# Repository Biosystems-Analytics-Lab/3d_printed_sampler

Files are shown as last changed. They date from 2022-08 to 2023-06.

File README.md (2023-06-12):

# 3D Printed Water Sampler

This repository includes materials for 3D printing a swinging water sample bottle holder. The sampler attachment holds a 1L sample bottle using a cable tie. The attachment screws on a standard telescoping pole (e.g., a paint roller pole). The sampler pivots such that the sample bottle can be easily filled with water. For each assembly, two washers, one bolt, and one nut with the following specs are required (all stainless steel):

- Bolts: ¼”-20 x 2-½”
- Nuts: ¼”-20
- Fender washers: ¼” x 1”

The `hardware.pdf` file includes images for the nuts, bolts, and washers we used to assemble the swing sampler.  

Be careful not to overtighten the threaded portion of the assembly onto a paint pole or other attachment. It may split the threaded body in half.

The design was created by Adam Rok and Jay Campbell in the Biological and Agricultural Engineering Department at NC State University in 2022. The designs were first published online on 26 Aug 2022.

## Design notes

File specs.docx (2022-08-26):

Bottle Holder

- Estimated printing time - Approx 12 hours
- Material:
  - Type - PLA, recommend ABS
  - Estimated amount - 127.4g, 42.71m
  - Estimated price - $3.82
- Print settings:
  - Nozzle temperature - 205 C
  - Bed temperature - 60 C
  - Layer height - 0.20mm
  - Infill density - 30
  - Infill pattern - Cubic
  - Bottom layers - 5
  - Top layers - 5
  - Shells - 2
  - Support for holes and overhangs
  - Raft - 5 layers, 3 solid

Threaded Mount

- Uses a 1/4-20 bolt as the connection / pivot point when attaching to the bottle holder
- Estimated printing time - Approx 3.5 hours
- Material:
  - Type - PLA, recommend ABS
  - Estimated amount - 39.0g, 13.08m
  - Estimated price - $1.17
- Print settings:
  - Nozzle temperature - 205 C
  - Bed temperature - 60 C
  - Layer height - 0.20mm
  - Infill density - 50
  - Infill pattern - Cubic
  - Bottom layers - 5
  - Top layers - 5
  - Shells - 2
  - Support used for hole and threads
  - Raft - 5 layers, 3 solid

Assembled Sampler

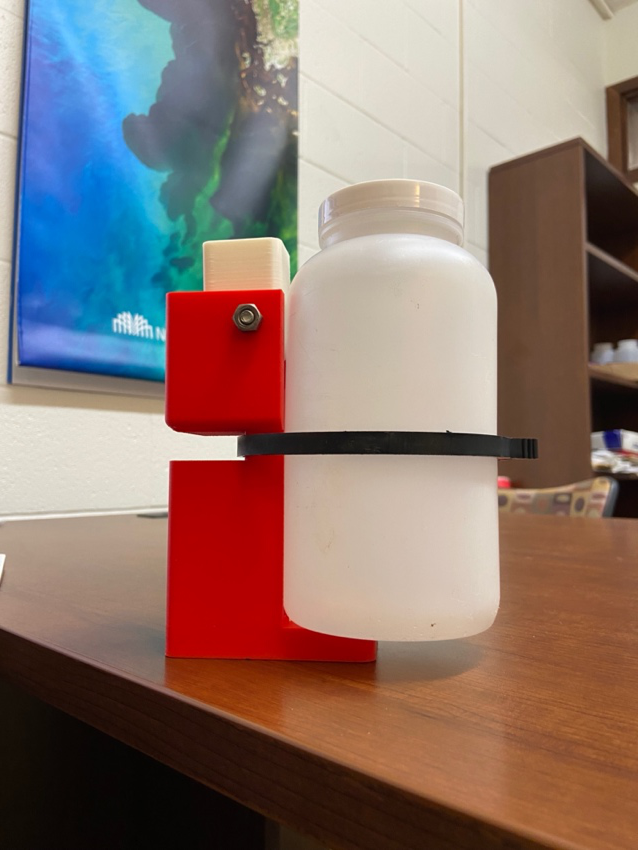
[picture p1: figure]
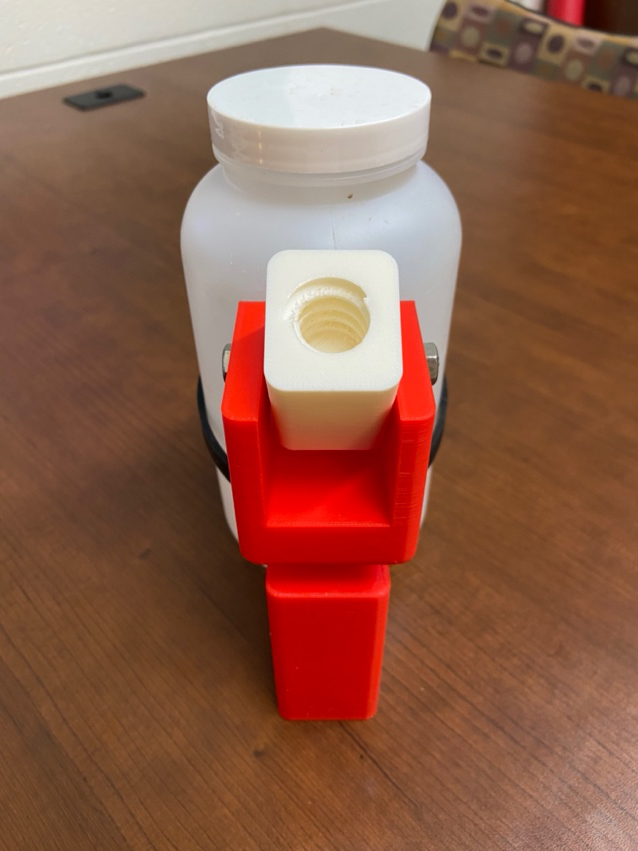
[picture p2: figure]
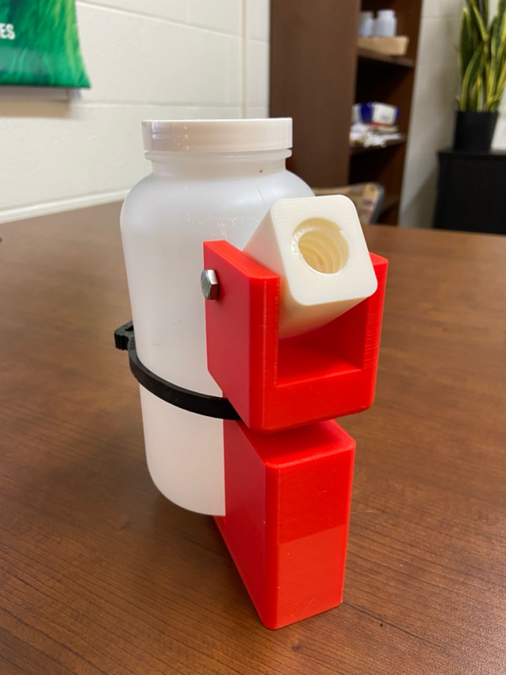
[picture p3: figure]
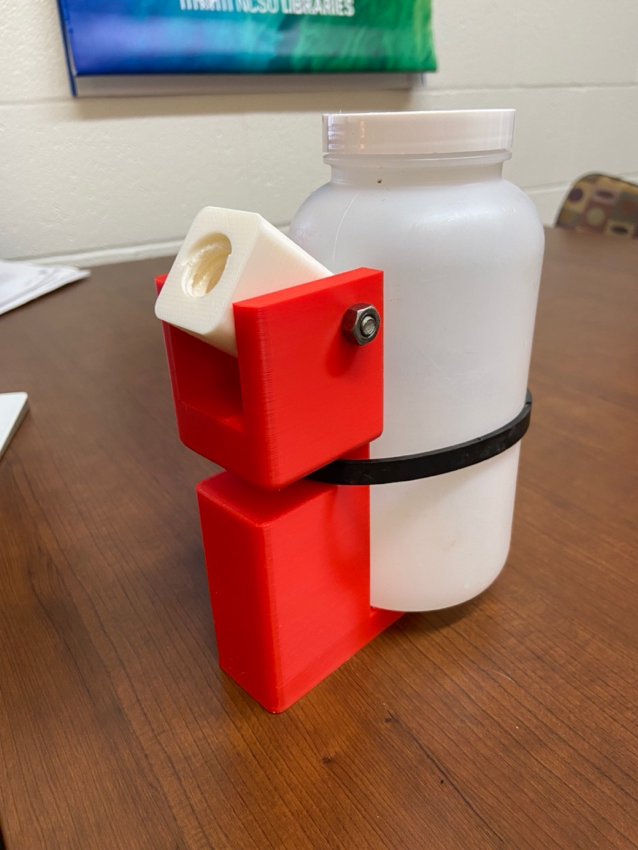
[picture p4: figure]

Printing Notes

- Temperature settings will need to be adjusted to print ABS materials:
  - Bed temperature - 100 C
  - Nozzle temperature - 250 C
- The 3D model file will be in .stl format and units are in inches.
- Prices are based on PLA filament, ABS will be more expensive but should be marginal.

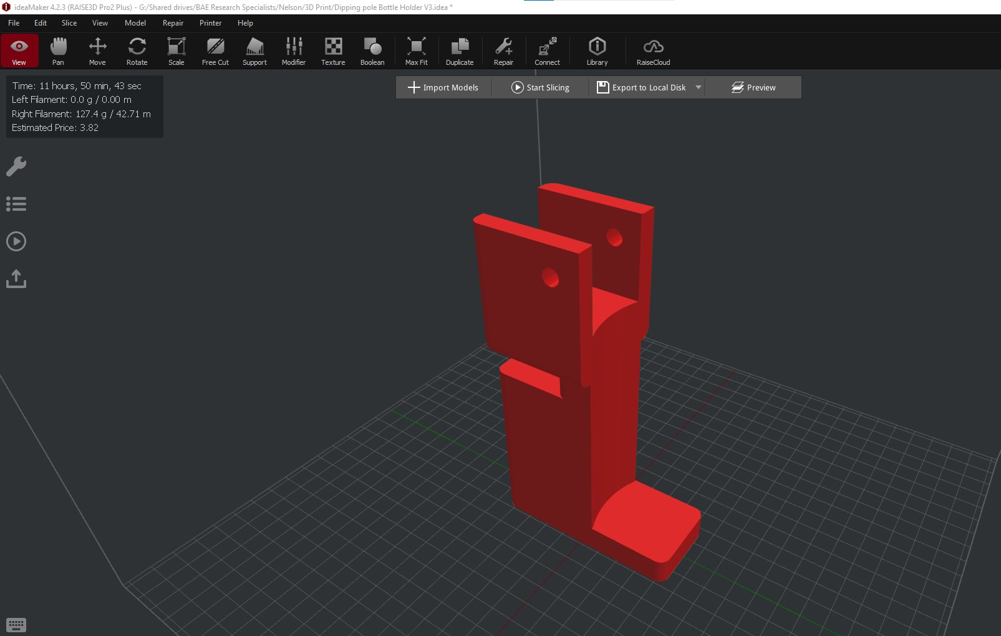
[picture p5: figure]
Image showing 3D model in the Idea maker environment.

3D model of bottle holder in the ideaMaker environment.

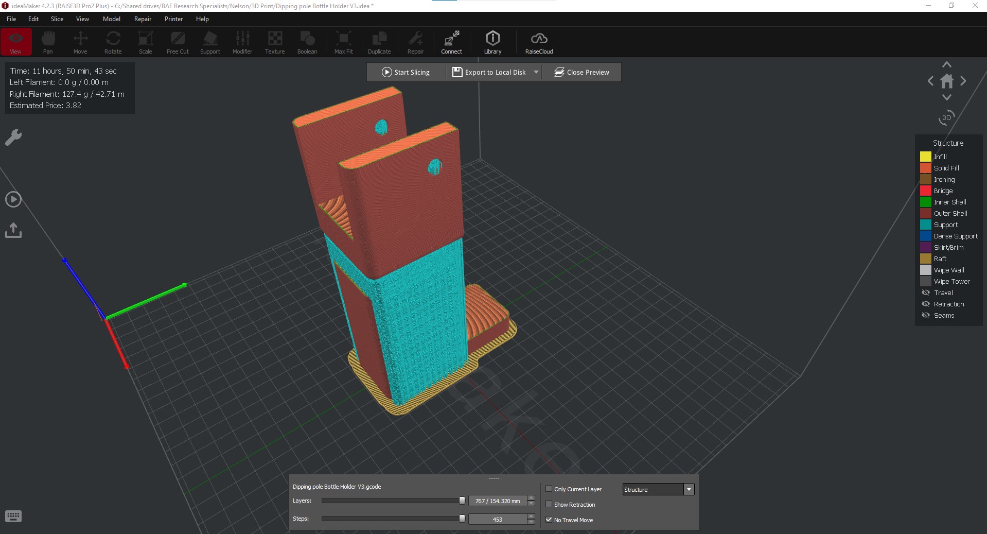
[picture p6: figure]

Model of bottle holder after it has been spliced to create a .Gcode file showing different types of printing structures.

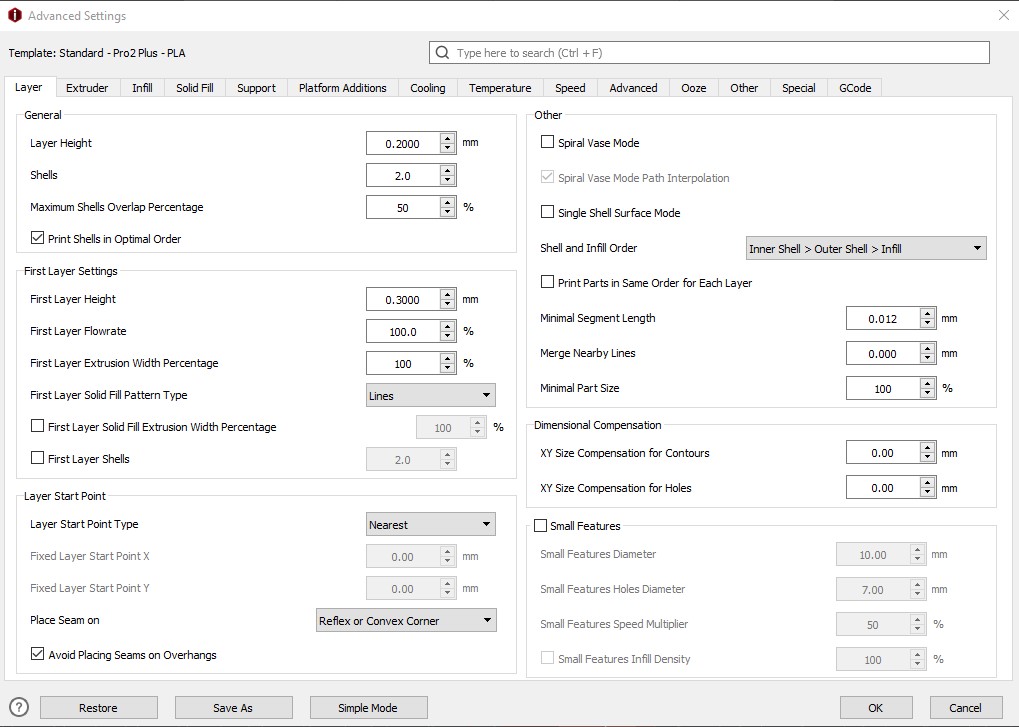
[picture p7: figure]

Layer settings.

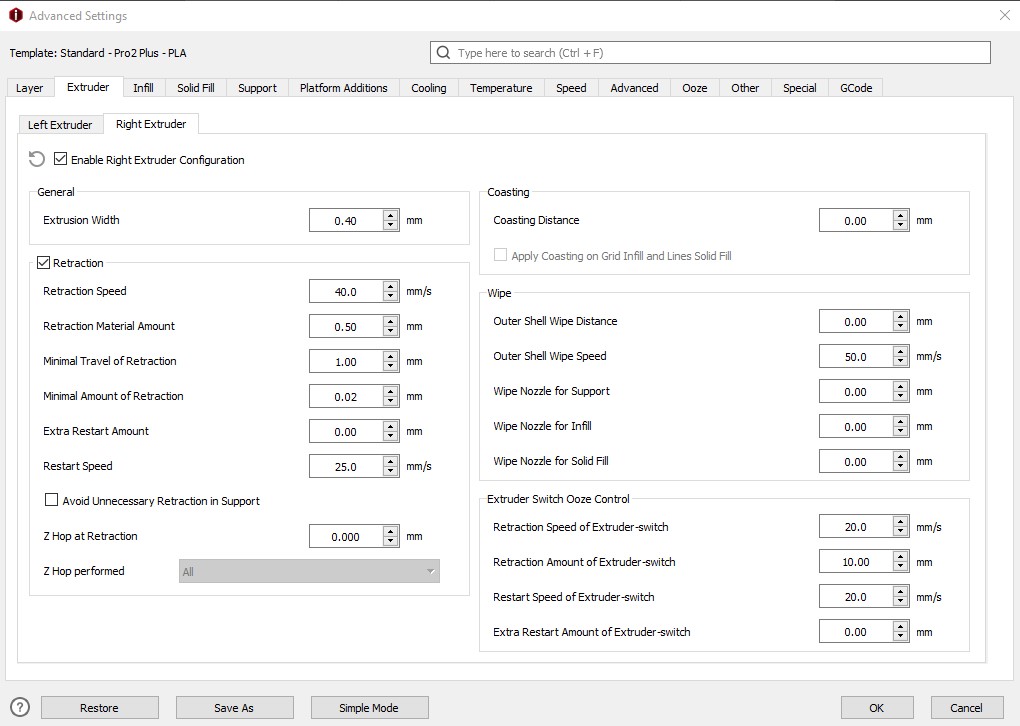
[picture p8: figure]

Extruder settings.

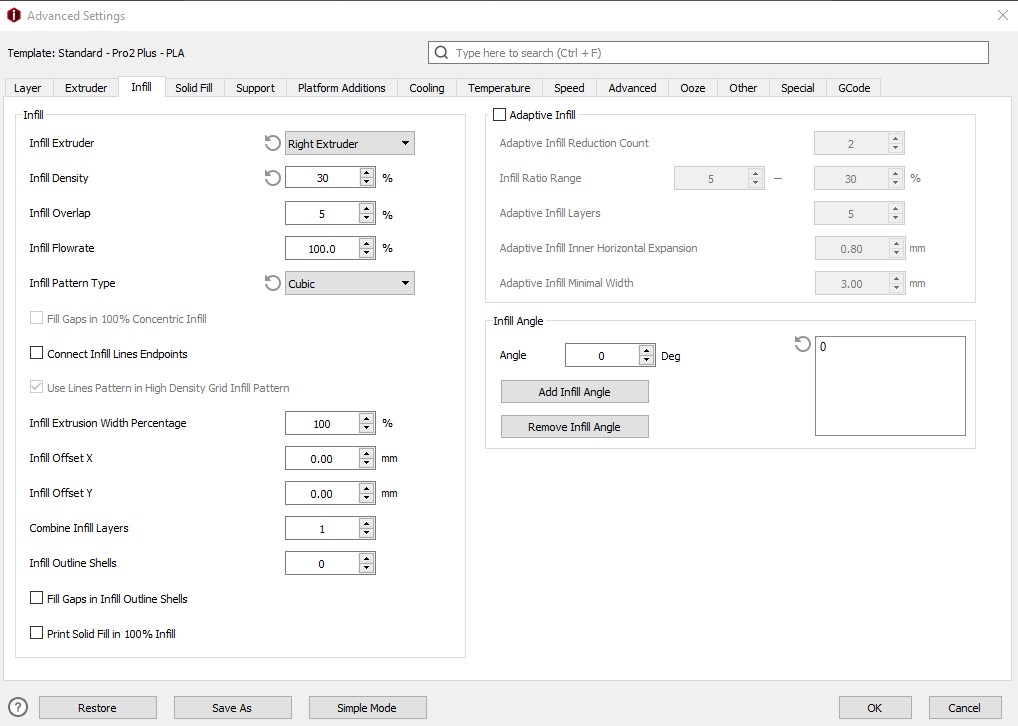
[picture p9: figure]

Infill settings.

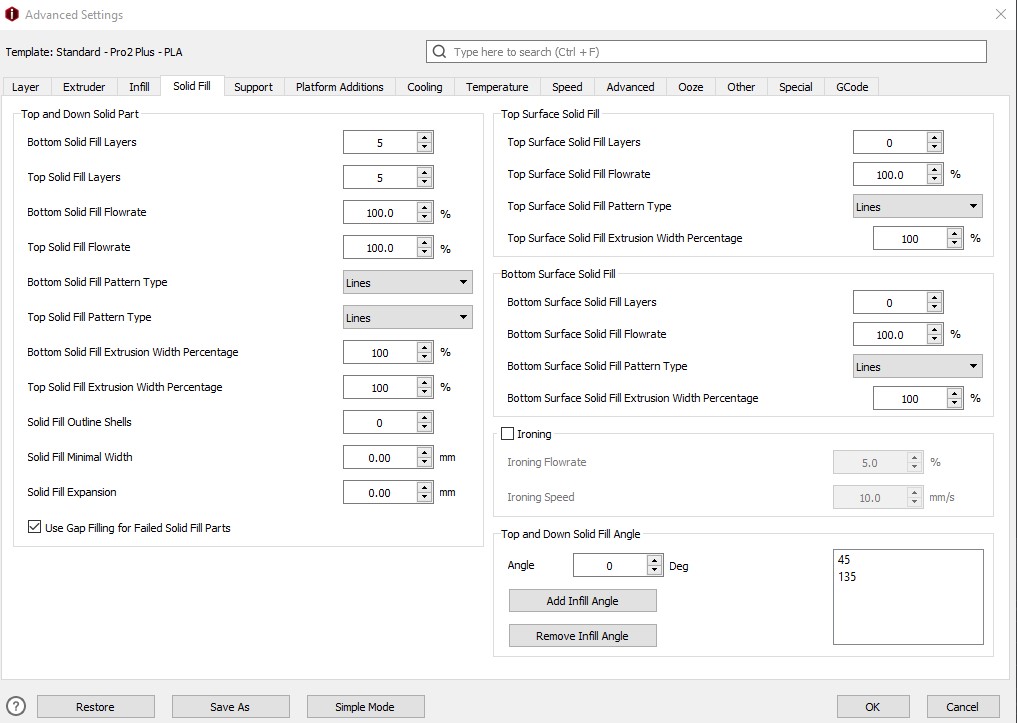
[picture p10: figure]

Solid fill settings.

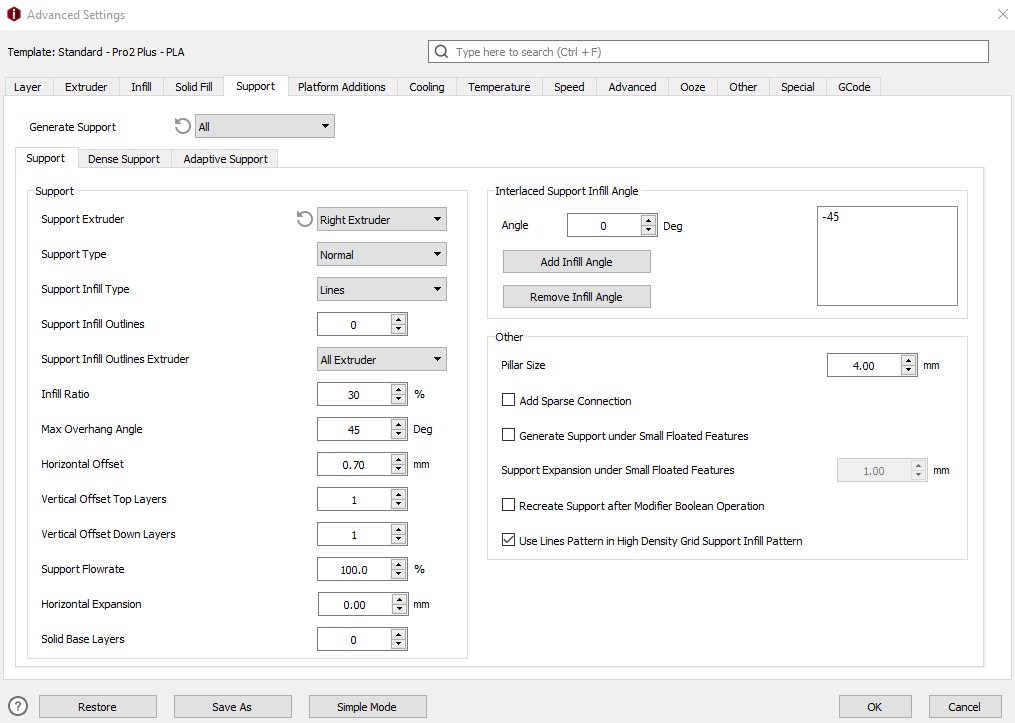
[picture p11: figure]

Support settings.

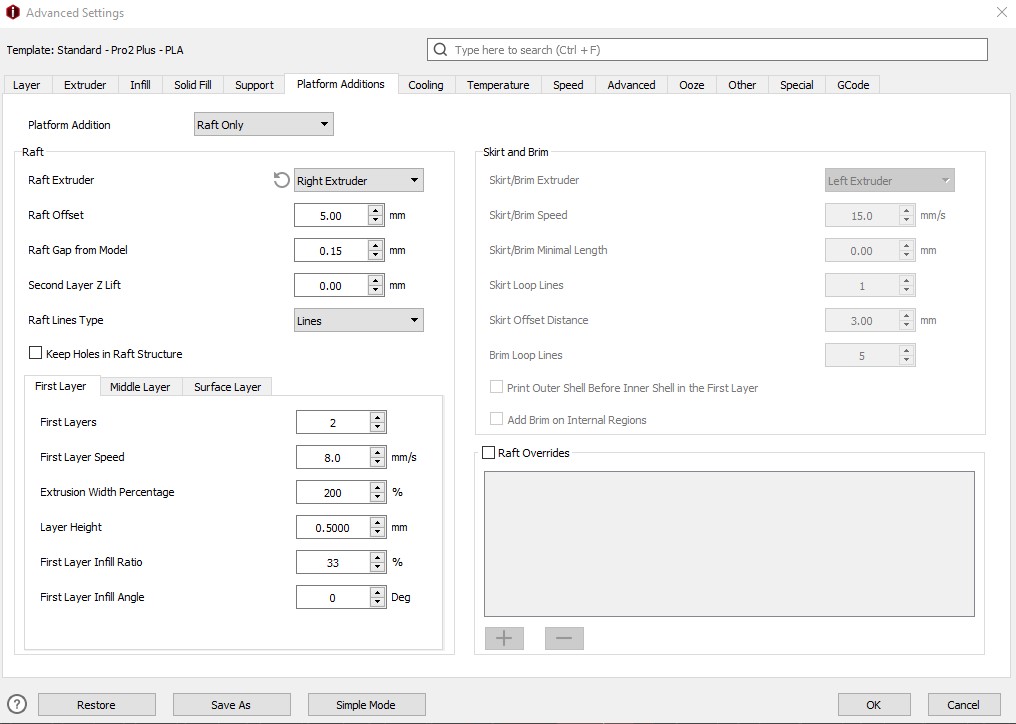
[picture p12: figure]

Raft settings.

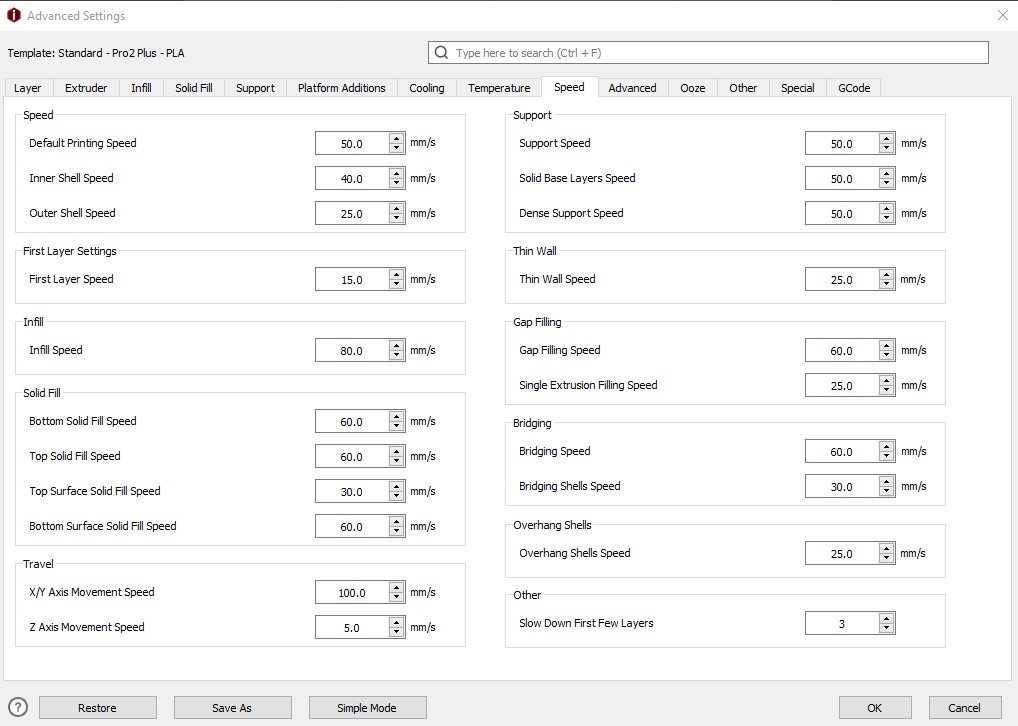
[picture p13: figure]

Speed settings.

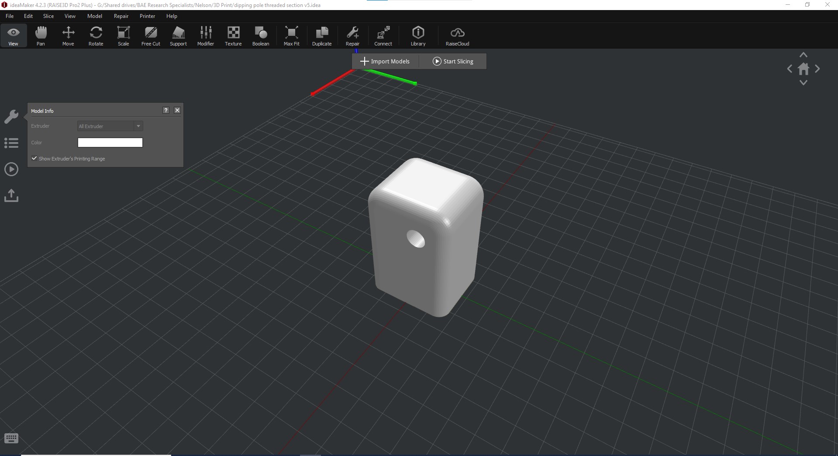
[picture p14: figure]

3D model of threaded mount in the ideaMaker environment.

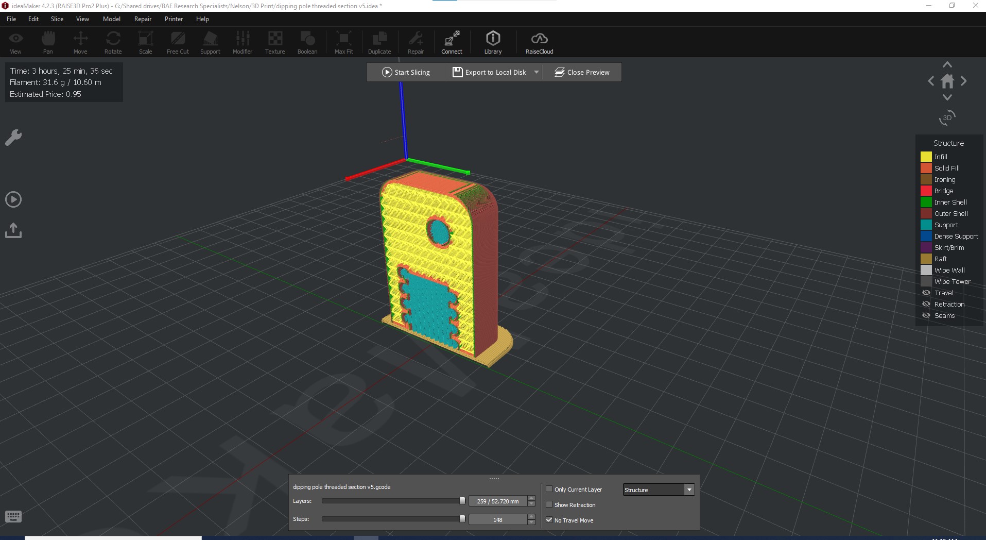
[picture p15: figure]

Cross section of threaded mount after slicing, showing support material (blue) inside threaded area and mounting hole. Cubic infill is also shown (yellow).

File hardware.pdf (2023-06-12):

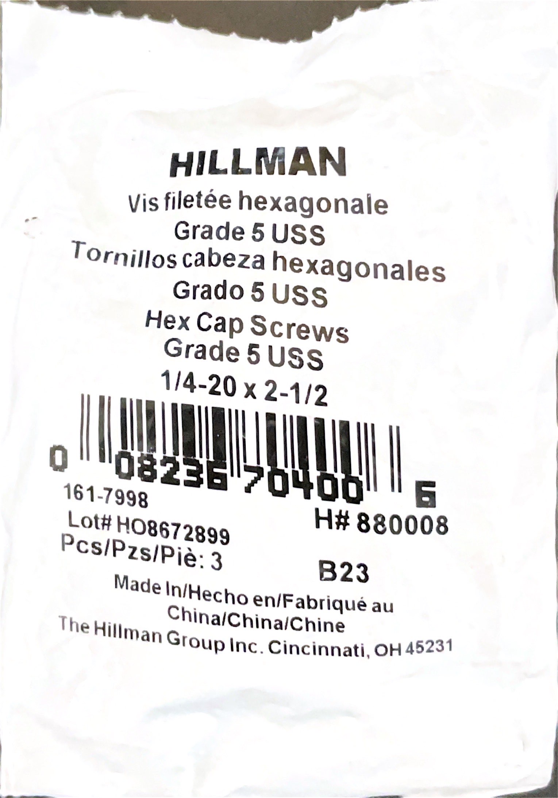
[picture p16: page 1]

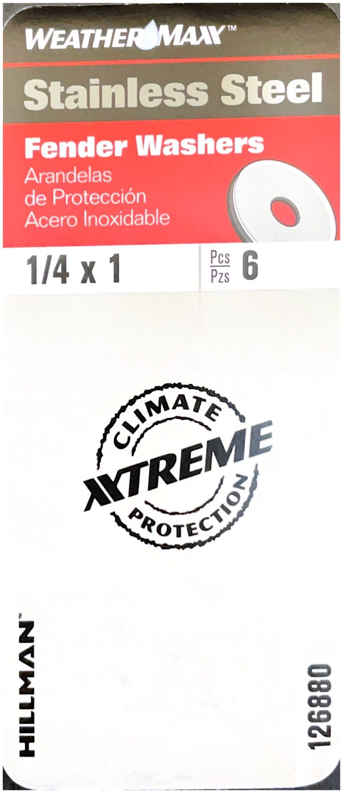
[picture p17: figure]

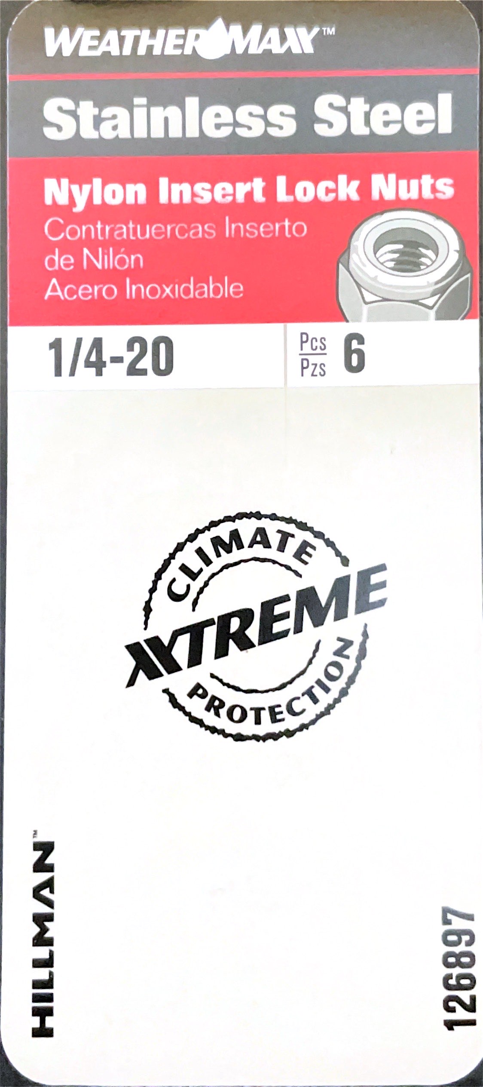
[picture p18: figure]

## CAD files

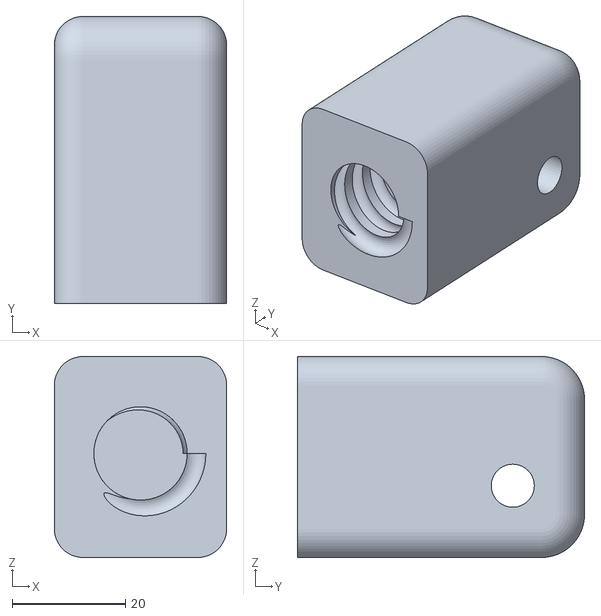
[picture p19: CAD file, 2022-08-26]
designs/dipping pole threaded section.stl
30.5 x 50.8 x 35.6

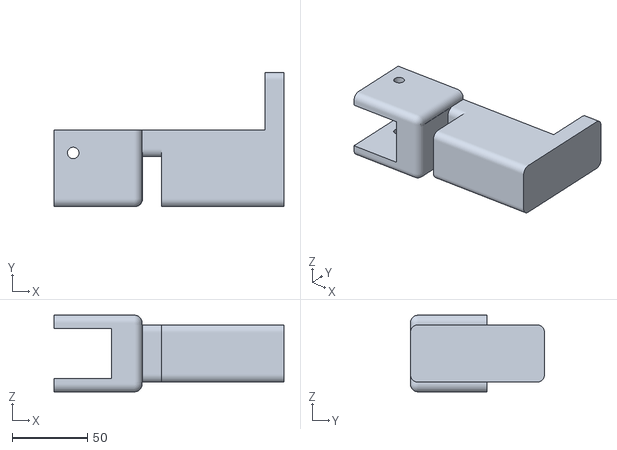
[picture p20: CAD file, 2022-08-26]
designs/dipping pole bottle holder.stl
152.4 x 88.9 x 50.8
